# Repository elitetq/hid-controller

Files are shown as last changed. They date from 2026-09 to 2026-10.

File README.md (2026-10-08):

# hid-controller

A custom USB gamepad built on an STM32F103, with a KiCad PCB and STM32 firmware. It has two analog sticks with click switches, a D-pad, face buttons, bumpers, digital triggers and Start/Share buttons.

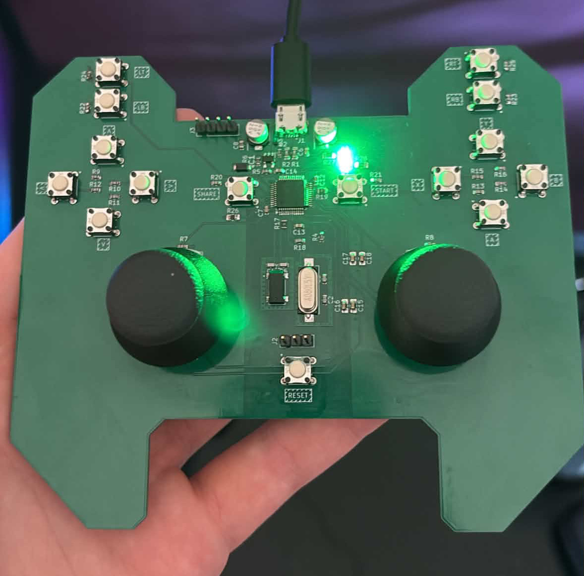
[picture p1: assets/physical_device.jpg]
Assembled controller


https://github.com/user-attachments/assets/c4e4d3e5-b4be-487b-b6eb-255510382f0a

## USB identity and compatibility

The device appears as **J-Controller**, with manufacturer **Jonart B** and VID:PID **1209:028e**. It sends custom HID gamepad reports. The controls follow an Xbox-style layout, but the firmware does not provide native XInput support.

Linux enumerates the controller. Windows only partly enumerates it so far. You can try [x360ce](https://www.x360ce.com/) for XInput mapping, but Windows needs to detect the controller first. There is no confirmed setup procedure for Windows yet.

## Files

| Path | Purpose |
| --- | --- |
| [hid-controller-pcb/](hid-controller-pcb/) | KiCad schematic, PCB, libraries and BOM |
| `hid-controller-pcb/production/hid-controller-pcb.zip` | Fabrication Gerbers |
| `hid-controller-code/hid-controller-code/` | Active firmware and Makefile |
| `Core/Src/main.c` inside the firmware folder | ADC sampling, button mapping and report updates |
| `USB_DEVICE/App/` inside the firmware folder | USB descriptors and HID interface |
| `usb-backup/` inside the firmware folder | Older firmware copy; not the Makefile's source tree |
| `assets/` | Photos, PCB layout and video |

## PCB and assembly

Open `hid-controller-pcb/hid-controller-pcb.kicad_pro` in KiCad. Review the schematic and layout before fabrication. The root board BOM is `hid-controller-pcb/BOM.csv`; production exports also include `production/bom.csv` and `production/positions.csv`. Match the BOM and placement export to the board revision you intend to assemble.

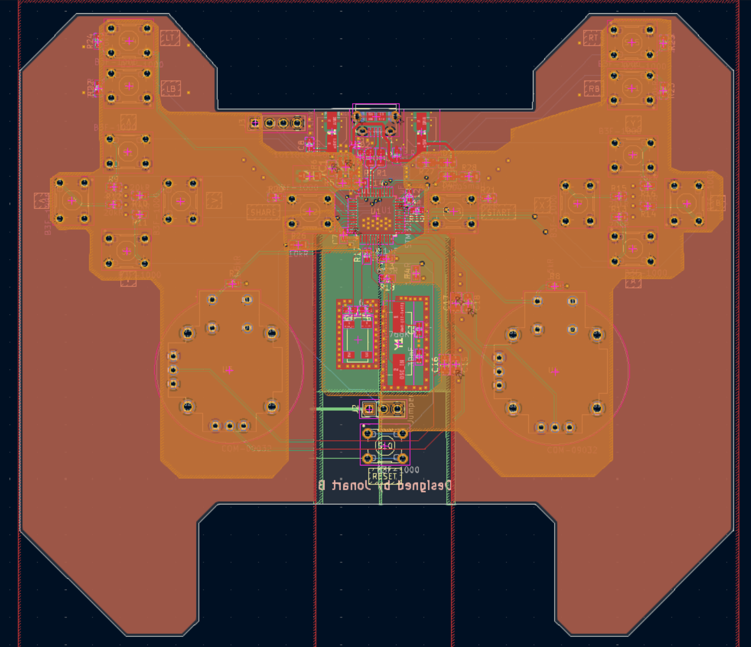
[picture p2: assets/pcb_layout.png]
PCB layout


Use the schematic's **SWDIO**, **SWCLK** and ground nets for the ST-Link connection, together with target-voltage reference as required by your probe. Check the actual connector orientation against the schematic rather than assuming a standard header pin order.

## Build

Requires GNU make, Arm GNU tools (`arm-none-eabi-gcc`, `objcopy` and `size`, including the C library/nano specs), and a POSIX shell for Makefile commands. Flashing requires ST-Link and [STM32CubeProgrammer](https://www.st.com/en/development-tools/stm32cubeprog.html), with `STM32_Programmer_CLI` on PATH.

**NOTE:** The firmware folder contains both `STM32F103XX_FLASH.ld` and `STM32F103xx_FLASH.ld`. They collide on a normal Windows filesystem. Use a case-sensitive filesystem (for example, a clone inside WSL's Linux filesystem) so both files can be checked out. The Makefile selects `STM32F103xx_FLASH.ld`.

```sh
git clone https://github.com/elitetq/hid-controller.git
cd hid-controller/hid-controller-code/hid-controller-code
make clean
make
```

The compiler path defaults to `/usr/bin/`. If your toolchain is elsewhere:

```sh
make GCC_PATH=/path/to/arm-toolchain/bin
```

Or, if the Arm tools are already on PATH, use `make GCC_PATH=`. The output is `build/hid-controller-code.elf`, with `.hex` and `.bin` versions alongside it. Clean first so checked-in build artifacts are not reused. There is no specific compiler/programmer version recorded for this build.

## Flash

Connect ST-Link to the powered target with common ground. From the firmware folder:

```sh
STM32_Programmer_CLI -c port=SWD -w build/hid-controller-code.elf -v -rst
```

This writes the ELF, verifies it and resets the device. The Makefile's `make flash` target contains a machine-specific Windows programmer path; use the command above or override `STMJLINKPATH` with your programmer executable. If you build in WSL, make sure the programmer can access ST-Link. You can also copy the ELF to Windows and flash it with STM32CubeProgrammer there.

## Check the inputs

1. Connect the controller's USB data port to the host. On Linux, `lsusb -d 1209:028e` can check enumeration; then check the inputs separately.
2. Open a gamepad input viewer. On Windows, start with **Win+R > joy.cpl** if the device appears there.
3. Move both sticks through their range and back to center. Check the D-pad, face buttons, bumpers, Start/Share and both stick clicks individually.
4. Press and release each trigger. These are digital switches: the firmware maps each trigger to 0 or 255, not an analog pressure range.
5. If using x360ce, confirm it detects the source device before mapping controls to a virtual controller and testing in a game. Failure to enumerate must be solved before mapping can help.

If inputs are missing, compare `gamepad_update_buttons()` and `gamepad_update_joysticks()` in `Core/Src/main.c` with the schematic and the report descriptor in `USB_DEVICE/App/usbd_custom_hid_if.c`. The two stick axes are swapped/inverted in software. Check the inputs on the assembled controller, as enumeration alone does not confirm that the mappings work.

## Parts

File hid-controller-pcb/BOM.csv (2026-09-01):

Reference | Value | MPN | QTY
C8,C9,C10,C11 | 10uF | CAPAE530X550N | 4
C2,C3 | 30pF | 06031U300GAT2A | 2
C4,C5 | 6pF | CBR06C609CAGAC | 2
C6,C7,C12,C13,C14 | 0.1uF | C0603C104K5RACTU | 5
D1 | 3.4V | SMF3.3 | 1
D2 | 6V | VESD05A1B-HD1-GS08 | 1
IC1 | RT9080-33GJ5 | RT9080-33GJ5 | 1
J1 | 10118194-0011LF | 10118194-0011LF | 1
J2 | Jumper | PRPC003SAAN-RC | 1
R1,R2 | 22R | RC0805FR-0722RL | 2
R3,R4,R7,R8 | 1.5kR | RMCF0603FT1K50 | 4
R5 | 68kR | RC0603FR-0768KL | 1
R6 | 13kR | RMCF0603FT13K0 | 1
R9,R10,R11,R12,R13,R14,R15,R16 | 20kR | RC0603FR-0720KL | 8
R17,R19 | 0R | RC0603JR-070RL | 2
R18 | 663R | RC0603FR-07665RL | 1
S1,S2,S3,S4,S5,S6,S7,S8,S10 | B3F-1000 | B3F-1000 | 12
U1 | STM32F103C8Tx | STM32F103C8Tx | 1
U3,U4 | COM-09032 | 9032 | 2
Y1 | 8MHz | ABLS-8.000MHZ-B4-T | 1
Y2 | 32.768KHz | ABS25-32.768KHZ-6-T | 1
C1 | 1uF | UMK107AB7105KA-T | 1
 | jumper short | QPC02SXGN-RC | 1

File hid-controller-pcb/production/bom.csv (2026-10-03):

Designator | Footprint | Quantity | Value | LCSC Part #
C1, C10 | CAPAE530X550N | 2 | 10uF
C12, C13, C14, C6, C7 | 0603 | 5 | 0.1uF
C15, C16, C17, C18 | 0805 | 4 | 0.1uF
C2, C3 | 0603 | 2 | 30pF
C4, C5 | 0603 | 2 | 6pF
C8 | 0603 | 1 | 1uF
D1 | SMFA2005CA | 1 | 3.4V
D2 | DIODE_VESD05A1B-HD1-GS08_VIS | 1 | 6V
D3, D4 | 0805 | 2 | LED
IC1 | RT9080-33GJ5 | 1 | RT9080-33GJ5
J1 | 10118194-0011LF | 1 | 10118194-0011LF
J2 | PinHeader_1x03_P2.54mm_Vertical | 1 | Jumper
J3 | PinHeader_1x04_P2.54mm_Vertical | 1 | STLink
R1, R2 | 0805 | 2 | 22R
R10, R11, R12, R13, R14, R15, R16, R20, R21, R22, R23, R24, R25, R9 | 0603 | 14 | 20kR
R17, R19 | 0603 | 2 | 0R
R18 | 0603 | 1 | 663R
R26 | 0805 | 1 | 10kR
R27, R28 | 0805 | 2 | R_Small
R3, R4, R7, R8 | 0603 | 4 | 1.5kR
R5 | 0603 | 1 | 68kR
R6 | 0603 | 1 | 13kR
S1, S10, S11, S12, S13, S14, S15, S2, S3, S4, S5, S6, S7, S8, S9 | SW_B3F-1000 | 15 | B3F-1000
U1 | LQFP-48_7x7mm_P0.5mm | 1 | STM32F103C8Tx
U3, U4 | XDCR_COM-09032 | 2 | COM-09032
Y1 | ABLS-8.000MHZ-B4-T | 1 | 8MHz
Y2 | XTAL_ABS25-32.768KHZ-6-T | 1 | 32.768KHz

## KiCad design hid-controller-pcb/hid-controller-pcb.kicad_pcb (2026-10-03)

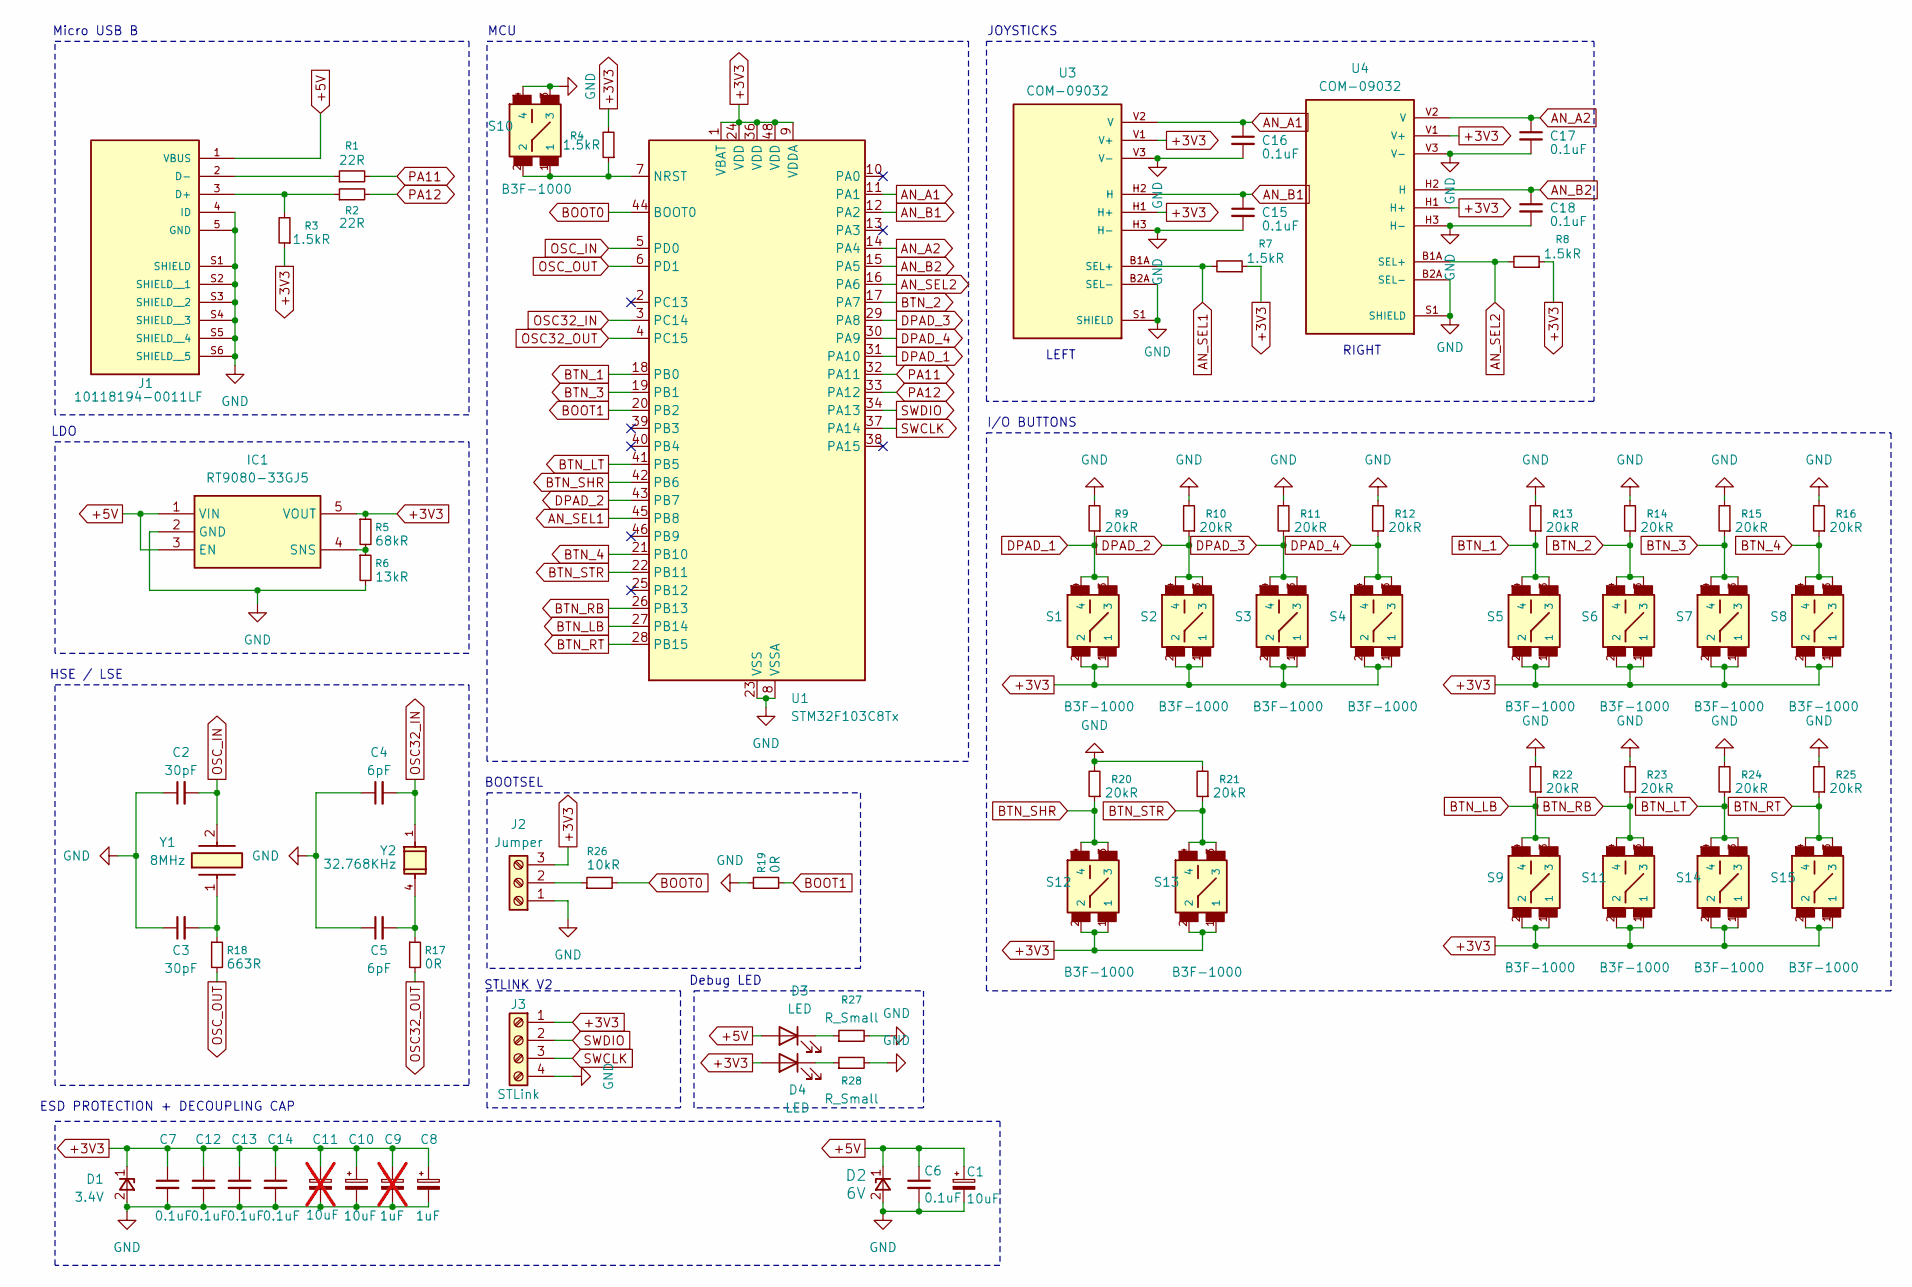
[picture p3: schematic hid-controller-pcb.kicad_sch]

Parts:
C1, C10: 10uF; CAPAE530X550N
C2, C3: 30pF; C_0603_1608Metric
C4, C5: 6pF; C_0603_1608Metric
C6, C7, C12, C13, C14: 0.1uF; C_0603_1608Metric
C8: 1uF; C_0603_1608Metric
C9: 1uF; C_0603_1608Metric; not fitted
C11: 10uF; CAPAE530X550N; not fitted
C15, C16, C17, C18: 0.1uF; C_0805_2012Metric_Pad1.18x1.45mm_HandSolder
D1: 3.4V; SMFA2005CA; Manufacturer_Part_Number SMF3.3; Mouser Part Number 576-SMF3.3
D2: 6V; DIODE_VESD05A1B-HD1-GS08_VIS
D3, D4: LED; LED_0805_2012Metric
IC1: RT9080-33GJ5; Manufacturer_Part_Number RT9080-33GJ5; Mouser Part Number 835-RT9080-33GJ5
J1: 10118194-0011LF; PARTREV D
J2: Jumper; PinHeader_1x03_P2.54mm_Vertical
J3: STLink; PinHeader_1x04_P2.54mm_Vertical
R1, R2: 22R; R_0805_2012Metric_Pad1.20x1.40mm_HandSolder
R3, R4, R7, R8: 1.5kR; R_0603_1608Metric
R5: 68kR; R_0603_1608Metric
R6: 13kR; R_0603_1608Metric
R9, R10, R11, R12, R13, R14, R15, R16, R20, R21, R22, R23, R24, R25: 20kR; R_0603_1608Metric
R17, R19: 0R; R_0603_1608Metric
R18: 663R; R_0603_1608Metric
R26: 10kR; R_0805_2012Metric_Pad1.20x1.40mm_HandSolder
R27, R28: R_Small; R_0805_2012Metric_Pad1.20x1.40mm_HandSolder
S1, S2, S3, S4, S5, S6, S7, S8, S9, S10, S11, S12, S13, S14, S15: B3F-1000; SW_B3F-1000
U1: STM32F103C8Tx; LQFP-48_7x7mm_P0.5mm
U3, U4: COM-09032; XDCR_COM-09032; PARTREV N/A
Y1: 8MHz; ABLS-8.000MHZ-B4-T; Manufacturer_Part_Number ABLS-8.000MHZ-B4-T; Mouser Part Number 815-ABLS-8.0M-T
Y2: 32.768KHz; XTAL_ABS25-32.768KHZ-6-T

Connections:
+3V3: C7.1, C8.1, C9.1, C10.1, C11.1, C12.1, C13.1, C14.1, D1.1 (K), D4.2 (A), IC1.5 (VOUT), J2.3, J3.1, R3.1, R4.2, R5.1, R7.1, R8.1, S1.1, S1.2, S2.1, S2.2, S3.1, S3.2, S4.1, S4.2, S5.1, S5.2, S6.1, S6.2, S7.1, S7.2, S8.1, S8.2, S9.1, S9.2, S11.1, S11.2, S12.1, S12.2, S13.1, S13.2, S14.1, S14.2, S15.1, S15.2, U1.1 (VBAT), U1.9 (VDDA), U1.24 (VDD), U1.36 (VDD), U1.48 (VDD), U3.H1 (H+), U3.V1 (V+), U4.H1 (H+), U4.V1 (V+)
+5V: C1.1, C6.1, D2.1, D3.2 (A), IC1.1 (VIN), IC1.3 (EN), J1.1 (VBUS)
AN_A1: C16.1, U1.11 (PA1), U3.V2 (V)
AN_A2: C17.1, U1.14 (PA4), U4.V2 (V)
AN_B1: C15.1, U1.12 (PA2), U3.H2 (H)
AN_B2: C18.1, U1.15 (PA5), U4.H2 (H)
AN_SEL1: R7.2, U1.45 (PB8), U3.B1A (SEL+)
AN_SEL2: R8.2, U1.16 (PA6), U4.B1A (SEL+)
BOOT0: R26.2, U1.44 (BOOT0)
BOOT1: R19.2, U1.20 (PB2)
BTN_1: R13.1, S5.3, S5.4, U1.18 (PB0)
BTN_2: R14.1, S6.3, S6.4, U1.17 (PA7)
BTN_3: R15.1, S7.3, S7.4, U1.19 (PB1)
BTN_4: R16.1, S8.3, S8.4, U1.21 (PB10)
BTN_LB: R22.1, S9.3, S9.4, U1.27 (PB14)
BTN_LT: R24.1, S14.3, S14.4, U1.41 (PB5)
BTN_RB: R23.1, S11.3, S11.4, U1.26 (PB13)
BTN_RT: R25.1, S15.3, S15.4, U1.28 (PB15)
BTN_SHR: R20.1, S12.3, S12.4, U1.42 (PB6)
BTN_STR: R21.1, S13.3, S13.4, U1.22 (PB11)
DPAD_1: R9.1, S1.3, S1.4, U1.31 (PA10)
DPAD_2: R10.1, S2.3, S2.4, U1.43 (PB7)
DPAD_3: R11.1, S3.3, S3.4, U1.29 (PA8)
DPAD_4: R12.1, S4.3, S4.4, U1.30 (PA9)
GND: C1.2, C2.1, C3.1, C4.1, C5.1, C6.2, C7.2, C8.2, C9.2, C10.2, C11.2, C12.2, C13.2, C14.2, C15.2, C16.2, C17.2, C18.2, D1.2 (A), D2.2, IC1.2 (GND), J1.4 (ID), J1.5 (GND), J1.S1 (SHIELD), J1.S2 (SHIELD__1), J1.S3 (SHIELD__2), J1.S4 (SHIELD__3), J1.S5 (SHIELD__4), J1.S6 (SHIELD__5), J2.1, J3.4, R6.2, R9.2, R10.2, R11.2, R12.2, R13.2, R14.2, R15.2, R16.2, R19.1, R20.2, R21.2, R22.2, R23.2, R24.2, R25.2, R27.2, R28.2, S10.3, S10.4, U1.8 (VSSA), U1.23 (VSS), U1.35 (VSS), U1.47 (VSS), U3.B2A (SEL-), U3.H3 (H-), U3.S1 (SHIELD), U3.S2 (SHIELD), U3.S3 (SHIELD), U3.S4 (SHIELD), U3.V3 (V-), U4.B2A (SEL-), U4.H3 (H-), U4.S1 (SHIELD), U4.S2 (SHIELD), U4.S3 (SHIELD), U4.S4 (SHIELD), U4.V3 (V-)
unnamed: C3.2, R18.1, Y1.1
unnamed: C5.2, R17.1, Y2.4
unnamed: D3.1 (K), R27.1
unnamed: D4.1 (K), R28.1
unnamed: IC1.4 (SNS), R5.2, R6.1
unnamed: J1.3 (D+), R2.1, R3.2
unnamed: J1.2 (D-), R1.1
unnamed: J2.2, R26.1
unnamed: R4.1, S10.1, S10.2, U1.7 (NRST)
OSC32_IN: C4.2, U1.3 (PC14), Y2.1
OSC32_OUT: R17.2, U1.4 (PC15)
OSC_IN: C2.2, U1.5 (PD0), Y1.2
OSC_OUT: R18.2, U1.6 (PD1)
PA11: R1.2, U1.32 (PA11)
PA12: R2.2, U1.33 (PA12)
SWCLK: J3.3, U1.37 (PA14)
SWDIO: J3.2, U1.34 (PA13)

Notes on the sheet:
MCU
Micro USB B
BOOTSEL
HSE / LSE
Debug LED
STLINK V2
RIGHT
LDO
LEFT
JOYSTICKS
I/O BUTTONS
ESD PROTECTION + DECOUPLING CAP

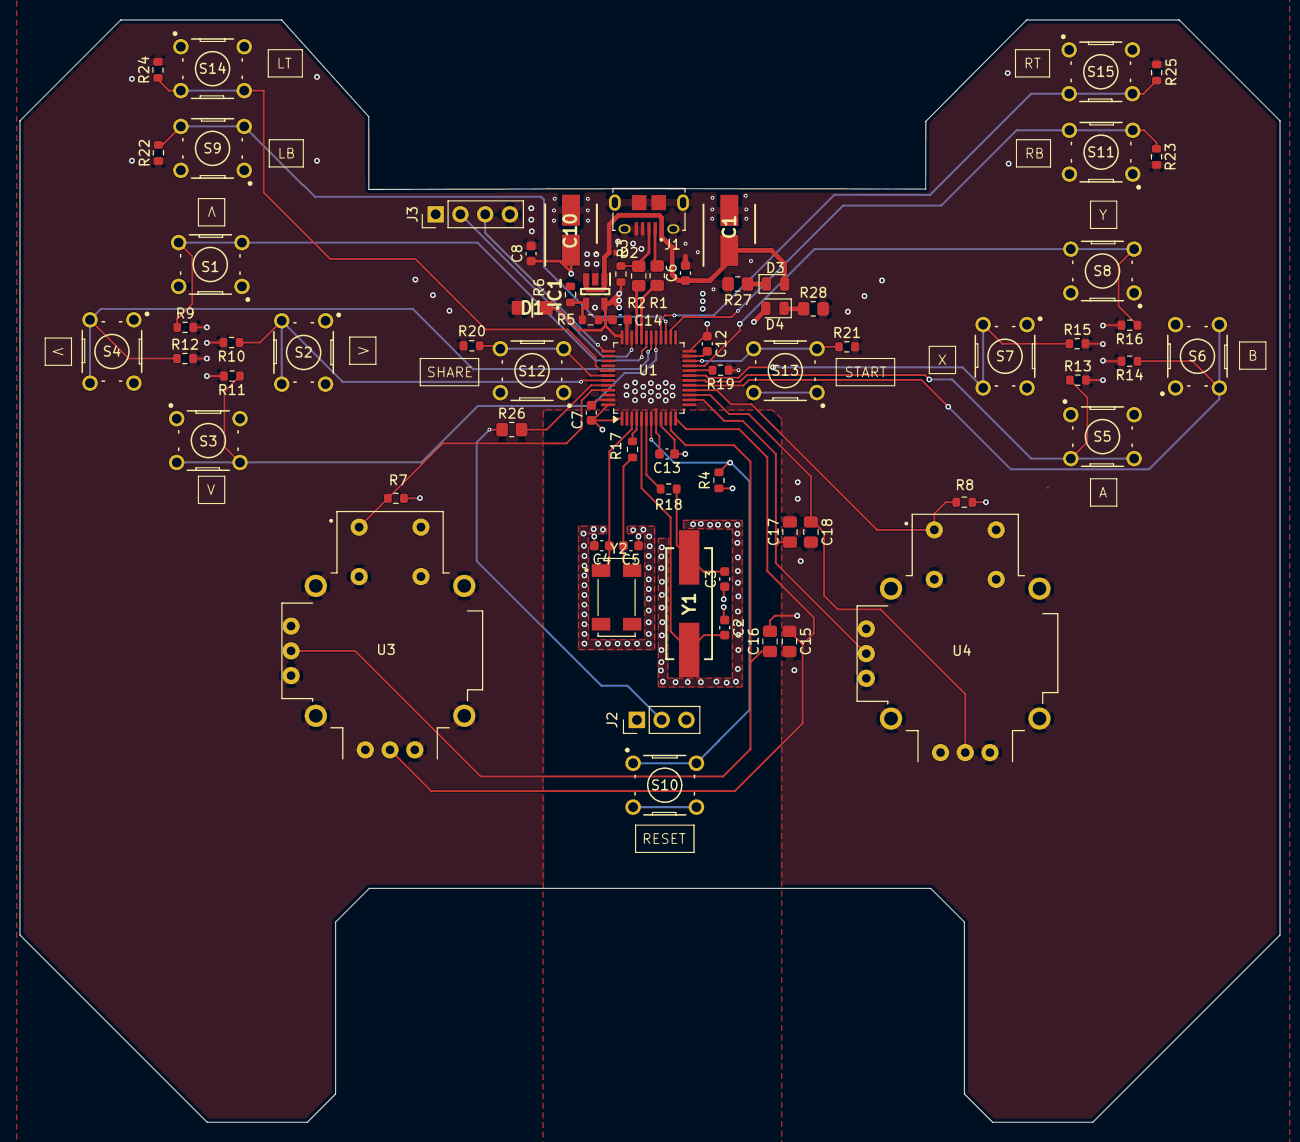
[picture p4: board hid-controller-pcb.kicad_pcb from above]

Board: 4 copper layers, 129.3 x 113.2 mm, 72 parts (0 on the bottom side), 42 nets.

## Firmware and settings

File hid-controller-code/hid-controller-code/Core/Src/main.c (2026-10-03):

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
/* Includes ------------------------------------------------------------------*/
#include "main.h"
#include "usb_device.h"

/* USER CODE BEGIN Includes */
#include "usbd_customhid.h"
#include "usbd_custom_hid_if.h"
/* USER CODE END Includes */

/* USER CODE BEGIN PTD */
/* Must match the HID report descriptor in usbd_custom_hid_if.c byte for byte. */
typedef struct __attribute__((packed))
{
  uint8_t  x;        /* left  stick X */
  uint8_t  y;        /* left  stick Y */
  uint8_t  lt;        /* triggers, 128 = centred, LT -> 0, RT -> 255 */
  uint8_t  rx;       /* right stick X */
  uint8_t  ry;       /* right stick Y */
  uint8_t  rt;
  uint8_t  hat;      /* d-pad, 8 = centred */
  uint16_t buttons;  /* bit 0..9 = button 1..10 */
} gamepad_report_t;
/* USER CODE END PTD */

/* USER CODE BEGIN PD */
#define JOYSTICK_OVERSAMPLE_BITS 4
#define JOYSTICK_OVERSAMPLE (1U << JOYSTICK_OVERSAMPLE_BITS)
/* USER CODE END PD */

ADC_HandleTypeDef hadc1;
DMA_HandleTypeDef hdma_adc1;

RTC_HandleTypeDef hrtc;

TIM_HandleTypeDef htim2;

/* USER CODE BEGIN PV */
static gamepad_report_t gamepad_report;
static volatile uint16_t joystick_buf[4 * JOYSTICK_OVERSAMPLE] = {0};
/* USER CODE END PV */

void SystemClock_Config(void);
static void MX_GPIO_Init(void);
static void MX_DMA_Init(void);
static void MX_ADC1_Init(void);
static void MX_RTC_Init(void);
static void MX_TIM2_Init(void);
/* USER CODE BEGIN PFP */
static void gamepad_update();

/* USER CODE END PFP */

/**
  * @brief  The application entry point.
  * @retval int
  */
int main(void)
{

  /* MCU Configuration--------------------------------------------------------*/

  /* Reset of all peripherals, Initializes the Flash interface and the Systick. */
  HAL_Init();

  /* Configure the system clock */
  SystemClock_Config();

  /* Initialize all configured peripherals */
  MX_GPIO_Init();
  MX_DMA_Init();
  MX_ADC1_Init();
  MX_USB_DEVICE_Init();
  MX_RTC_Init();
  MX_TIM2_Init();
  /* USER CODE BEGIN 2 */
  HAL_ADCEx_Calibration_Start(&hadc1);
  HAL_ADC_Start_DMA(&hadc1,(uint32_t*)joystick_buf,4*JOYSTICK_OVERSAMPLE);
  gamepad_report.buttons = 0x0000; // 10101010 temp
  gamepad_report.rt = 128;        // triggers released - 0 would read as LT held
  gamepad_report.lt = 128;        // triggers released - 0 would read as LT held
  gamepad_report.hat = 8;

  /* USER CODE END 2 */

  /* Infinite loop */
  /* USER CODE BEGIN WHILE */
  while (1)
  {
    /* USER CODE END WHILE */

    /* USER CODE BEGIN 3 */
    gamepad_update();
    USBD_CUSTOM_HID_SendReport_FS((uint8_t*)&gamepad_report,sizeof(gamepad_report));
  }
  /* USER CODE END 3 */
}

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
/* USER CODE BEGIN 4 */
static void gamepad_update_joysticks() {
  uint32_t avg_x, avg_y, avg_rx, avg_ry;
  avg_x = avg_y = avg_rx = avg_ry = 0;
  for(uint32_t i = 0; i < JOYSTICK_OVERSAMPLE; i++) {
    avg_x += joystick_buf[i*4];
    avg_y += joystick_buf[i*4+1];
    avg_rx += joystick_buf[i*4+2];
    avg_ry += joystick_buf[i*4+3];
  }
  gamepad_report.x = 255 - (avg_y >> (JOYSTICK_OVERSAMPLE_BITS+4));
  gamepad_report.rx = 255 - (avg_ry >> (JOYSTICK_OVERSAMPLE_BITS+4));
  gamepad_report.y = 255 - (avg_x >> (JOYSTICK_OVERSAMPLE_BITS+4));
  gamepad_report.ry = 255 - (avg_rx >> (JOYSTICK_OVERSAMPLE_BITS+4));
}

// num > 0 && num < 11
static void gamepad_set_button(uint8_t num, uint8_t val) {
  uint16_t bitmask = 0x0001 << (num-1);
  if(val)
    gamepad_report.buttons |= bitmask;
  else
    gamepad_report.buttons &= ~bitmask;
}

static int get_dpad(uint8_t dpad_right, uint8_t dpad_down, uint8_t dpad_left, uint8_t dpad_up) {
  if(dpad_up) {
    if(dpad_right) return 1;
    else if(dpad_left) return 7;
    return 0;
  } else if(dpad_right) {
    return dpad_down + 2; // E - SE
  } else if(dpad_down) {
    return dpad_left + 4; // S - SW
  } else if(dpad_left) {
    return 6;
  }
  return 8; // no direction
}

static void gamepad_update_buttons() {
  gamepad_report.buttons = 0;
  gamepad_set_button(1,(uint8_t)HAL_GPIO_ReadPin(GPIOB,GPIO_PIN_0)); // A
  gamepad_set_button(2,(uint8_t)HAL_GPIO_ReadPin(GPIOA,GPIO_PIN_7)); // B
  gamepad_set_button(5,(uint8_t)HAL_GPIO_ReadPin(GPIOB,GPIO_PIN_1)); // X
  gamepad_set_button(4,(uint8_t)HAL_GPIO_ReadPin(GPIOB,GPIO_PIN_10)); // Y
  gamepad_set_button(7,(uint8_t)HAL_GPIO_ReadPin(GPIOB,GPIO_PIN_14)); // LB
  gamepad_set_button(8,(uint8_t)HAL_GPIO_ReadPin(GPIOB,GPIO_PIN_13)); // RB
  gamepad_report.lt = HAL_GPIO_ReadPin(GPIOB,GPIO_PIN_5) ? 255 : 0;  // LT
  gamepad_report.rt = HAL_GPIO_ReadPin(GPIOB,GPIO_PIN_15) ? 255 : 0;  // RT
  gamepad_set_button(11,(uint8_t)HAL_GPIO_ReadPin(GPIOB,GPIO_PIN_6)); // Back/Share
  gamepad_set_button(12,(uint8_t)HAL_GPIO_ReadPin(GPIOB,GPIO_PIN_11)); // Start
  gamepad_set_button(14,!(uint8_t)HAL_GPIO_ReadPin(GPIOB,GPIO_PIN_8)); // LClick
  gamepad_set_button(15,!(uint8_t)HAL_GPIO_ReadPin(GPIOA,GPIO_PIN_6)); // RClick
  gamepad_report.hat = get_dpad(
              (uint8_t)HAL_GPIO_ReadPin(GPIOB,GPIO_PIN_7),
              (uint8_t)HAL_GPIO_ReadPin(GPIOA,GPIO_PIN_8),
              (uint8_t)HAL_GPIO_ReadPin(GPIOA,GPIO_PIN_9),
              (uint8_t)HAL_GPIO_ReadPin(GPIOA,GPIO_PIN_10)
  );
  return;
}

static void gamepad_update() {
  gamepad_update_joysticks();
  gamepad_update_buttons();
}

/* USER CODE END 4 */
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


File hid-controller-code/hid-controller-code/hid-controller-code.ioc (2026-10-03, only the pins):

Mcu.UserName=STM32F103C8Tx
PA1.Signal=ADCx_IN1
PA10.Signal=GPIO_Input
PA11.Signal=USB_DM
PA12.Signal=USB_DP
PA13.Signal=SYS_JTMS-SWDIO
PA14.Signal=SYS_JTCK-SWCLK
PA2.Signal=ADCx_IN2
PA4.Signal=ADCx_IN4
PA5.Signal=ADCx_IN5
PA6.Signal=GPIO_Input
PA7.Signal=GPIO_Input
PA8.Signal=GPIO_Input
PA9.Signal=GPIO_Input
PB0.Signal=GPIO_Input
PB1.Signal=GPIO_Input
PB10.Signal=GPIO_Input
PB11.Signal=GPIO_Input
PB13.Signal=GPIO_Input
PB14.Signal=GPIO_Input
PB15.Signal=GPIO_Input
PB5.Signal=GPIO_Input
PB6.Signal=GPIO_Input
PB7.Signal=GPIO_Input
PB8.Signal=GPIO_Input
PC14-OSC32_IN.Signal=RCC_OSC32_IN
PC15-OSC32_OUT.Signal=RCC_OSC32_OUT
PD0-OSC_IN.Signal=RCC_OSC_IN
PD1-OSC_OUT.Signal=RCC_OSC_OUT

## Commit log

2026-08-23 init commit
    [hid-controller-pcb.kicad_pcb, hid-controller-pcb.kicad_sch]
2026-08-23 HSE / LSE finished, onto analog
    [hid-controller-pcb.kicad_pcb, hid-controller-pcb.kicad_sch]
2026-08-27 Added joysticks / buttons, made STM32CubeMX project
    [hid-controller-pcb.kicad_pcb]
2026-08-27 schematic finished? now onto layout
    [hid-controller-pcb.kicad_pcb, hid-controller-pcb.kicad_sch]
2026-08-28 gruelling layout work on the LSE / HSE oscillators
    [hid-controller-pcb.kicad_pcb, hid-controller-pcb.kicad_sch]
2026-08-30 stop tracking build output and kicad lock files
2026-08-30 working ADC reading, troubleshooting USB enumeration issues on pc
    [hid-controller-pcb.kicad_pcb, hid-controller-pcb.kicad_sch]
2026-08-30 Working enumeration! Just not recognizing as a generic controller on some sites, added hat switch
2026-09-01 working with xbox360ce remapping as a workaround for now, more work on the pcb
    [hid-controller-pcb.kicad_pcb, hid-controller-pcb.kicad_sch]
2026-09-03 switched to 4 layer board, too many traces :(
    [hid-controller-pcb.kicad_pcb, hid-controller-pcb.kicad_sch]
2026-09-03 further work on controller
    [hid-controller-pcb.kicad_pcb, hid-controller-pcb.kicad_sch]
2026-09-04 Controller layout done! Reviewing before sending to JLC
    [bom.csv, designators.csv, hid-controller-pcb.kicad_pcb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]
2026-09-06 final version of controller v1.0
    [bom.csv, designators.csv, hid-controller-pcb.kicad_pcb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]
2026-10-03 makefile linux gcc path fix
    [bom.csv, designators.csv, hid-controller-pcb.kicad_pcb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]
2026-10-03 Working firmware for USB enumeration on Linux and partly enumerates on windows with xbox 360 ce workaround.
    [hid-controller-code.ioc, main.c]

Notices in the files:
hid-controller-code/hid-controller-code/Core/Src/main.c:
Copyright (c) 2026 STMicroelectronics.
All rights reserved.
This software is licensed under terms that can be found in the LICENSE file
